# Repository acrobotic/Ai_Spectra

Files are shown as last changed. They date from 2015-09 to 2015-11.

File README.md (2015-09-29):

## Ai\_Spectra

PCB design files (EAGLE) for an interactive Light+Sound Electronics Board 
carrying 48 RGB LEDs, sensors, and a speaker for displaying custom audiovisual
patterns. 

## Description

For more details, check out the product page at:

   * https://acrobotic.com/acr-00018

Designed by ACROBOTIC Industries.  Please consider buying products from us to 
help fund future Open-Source projects like this! We’ll always put our best 
effort in every project, and release all our design files and code for you to 
use. 

## License

Released under the Creative Commons Attribution, Share-Alike license. Please 
check LICENSE.txt for more information. All text above must be included in any 
redistribution.

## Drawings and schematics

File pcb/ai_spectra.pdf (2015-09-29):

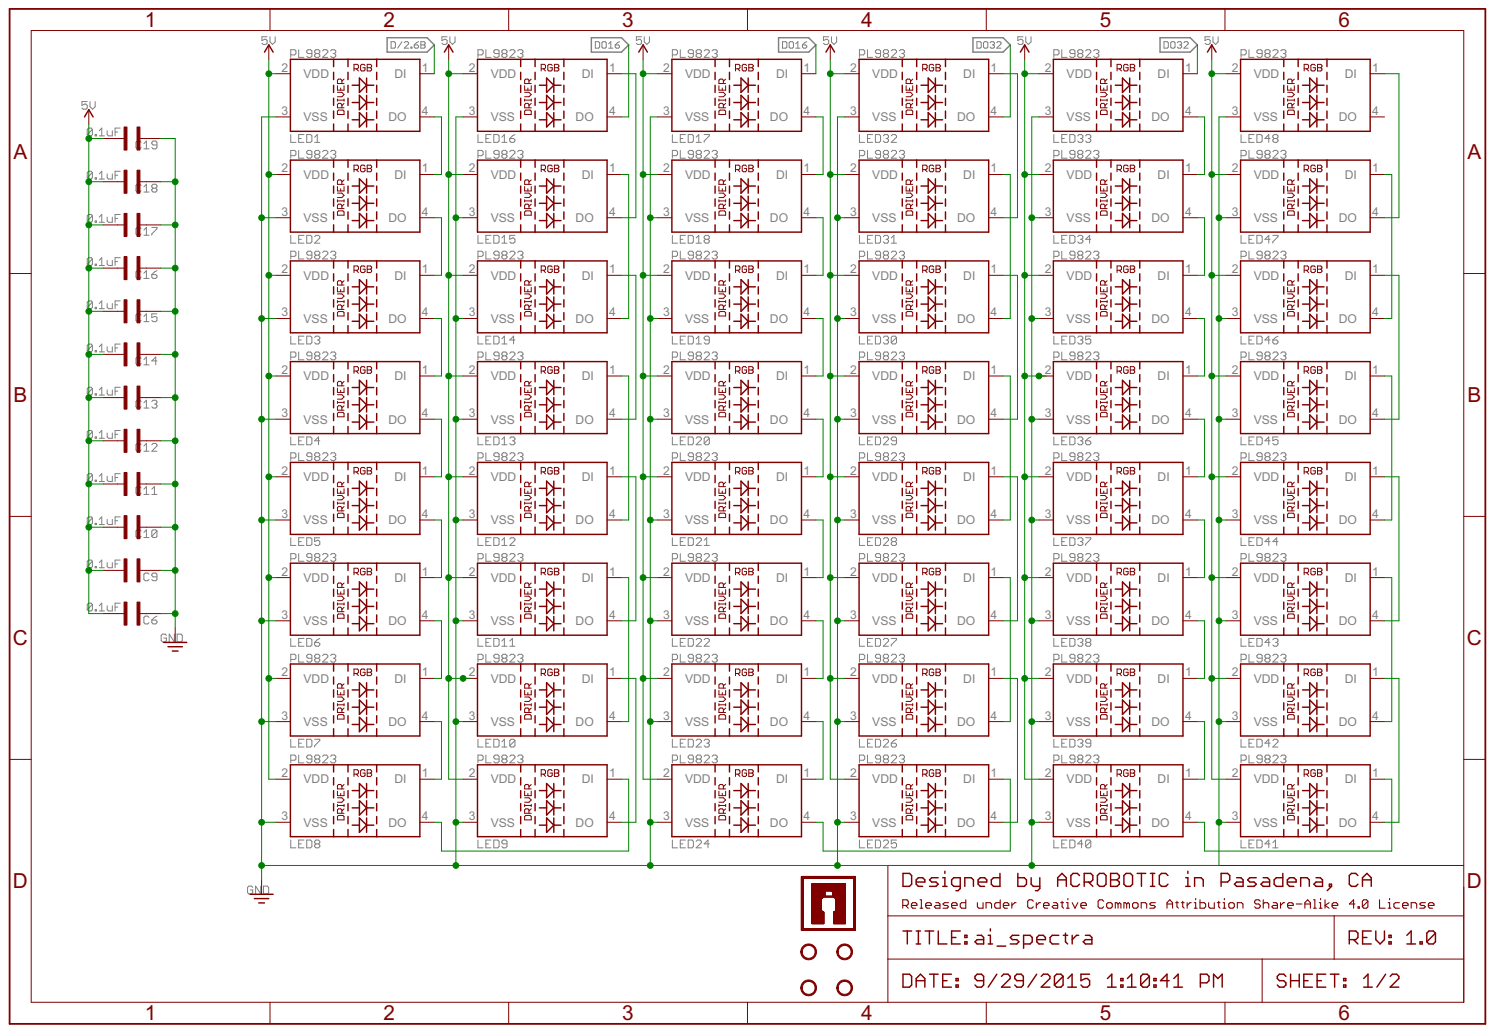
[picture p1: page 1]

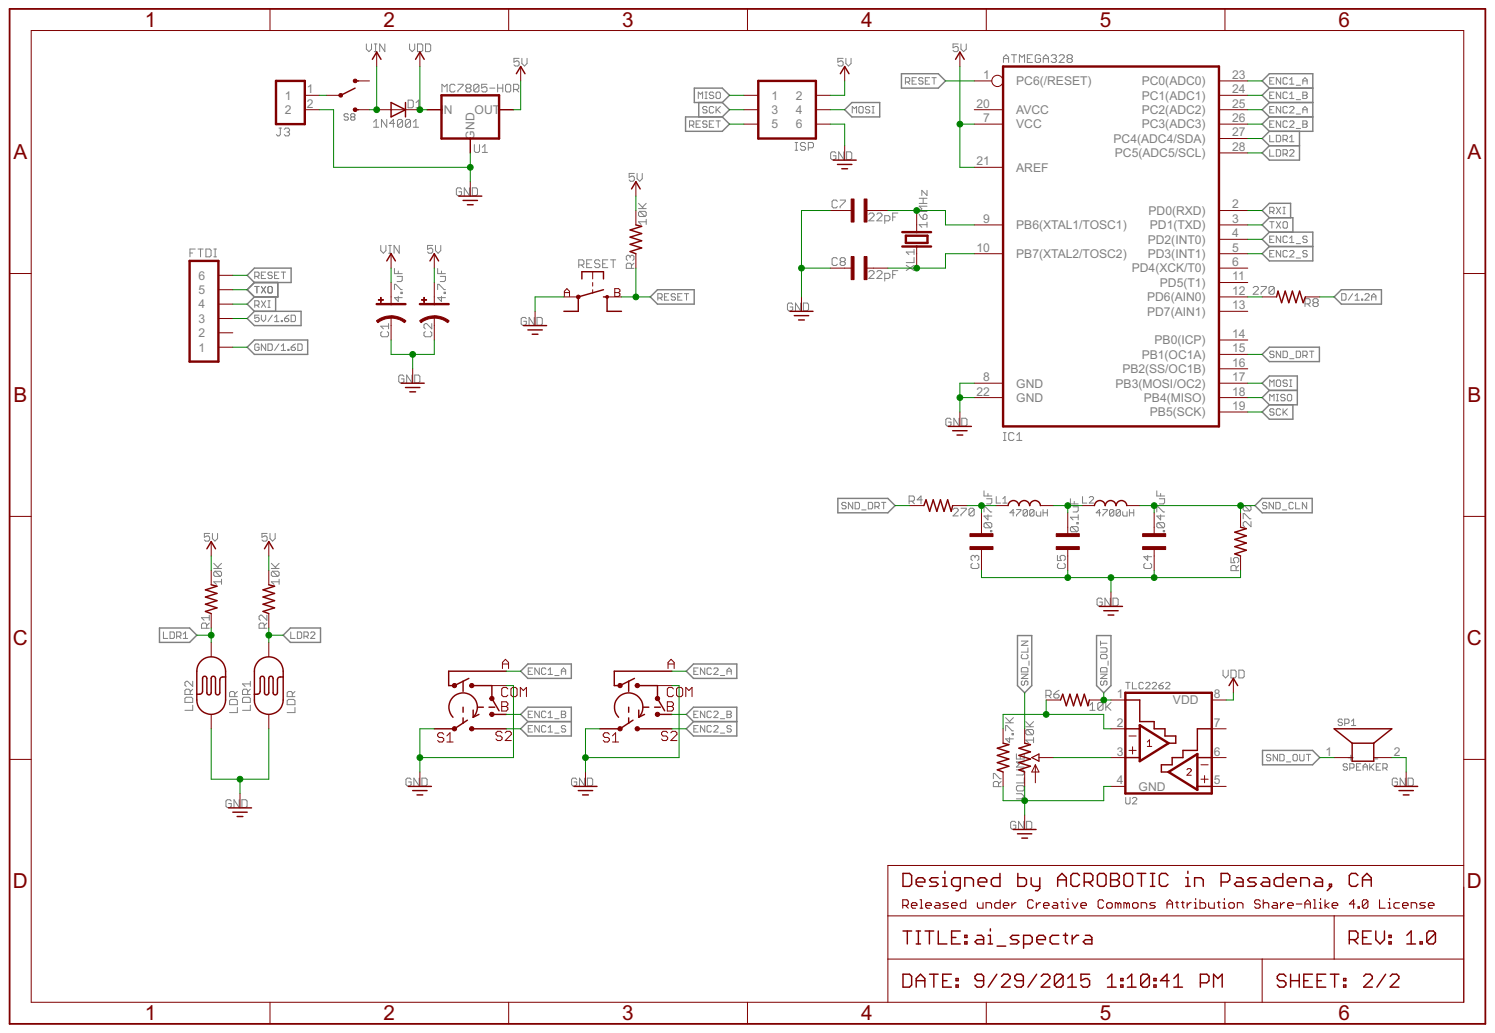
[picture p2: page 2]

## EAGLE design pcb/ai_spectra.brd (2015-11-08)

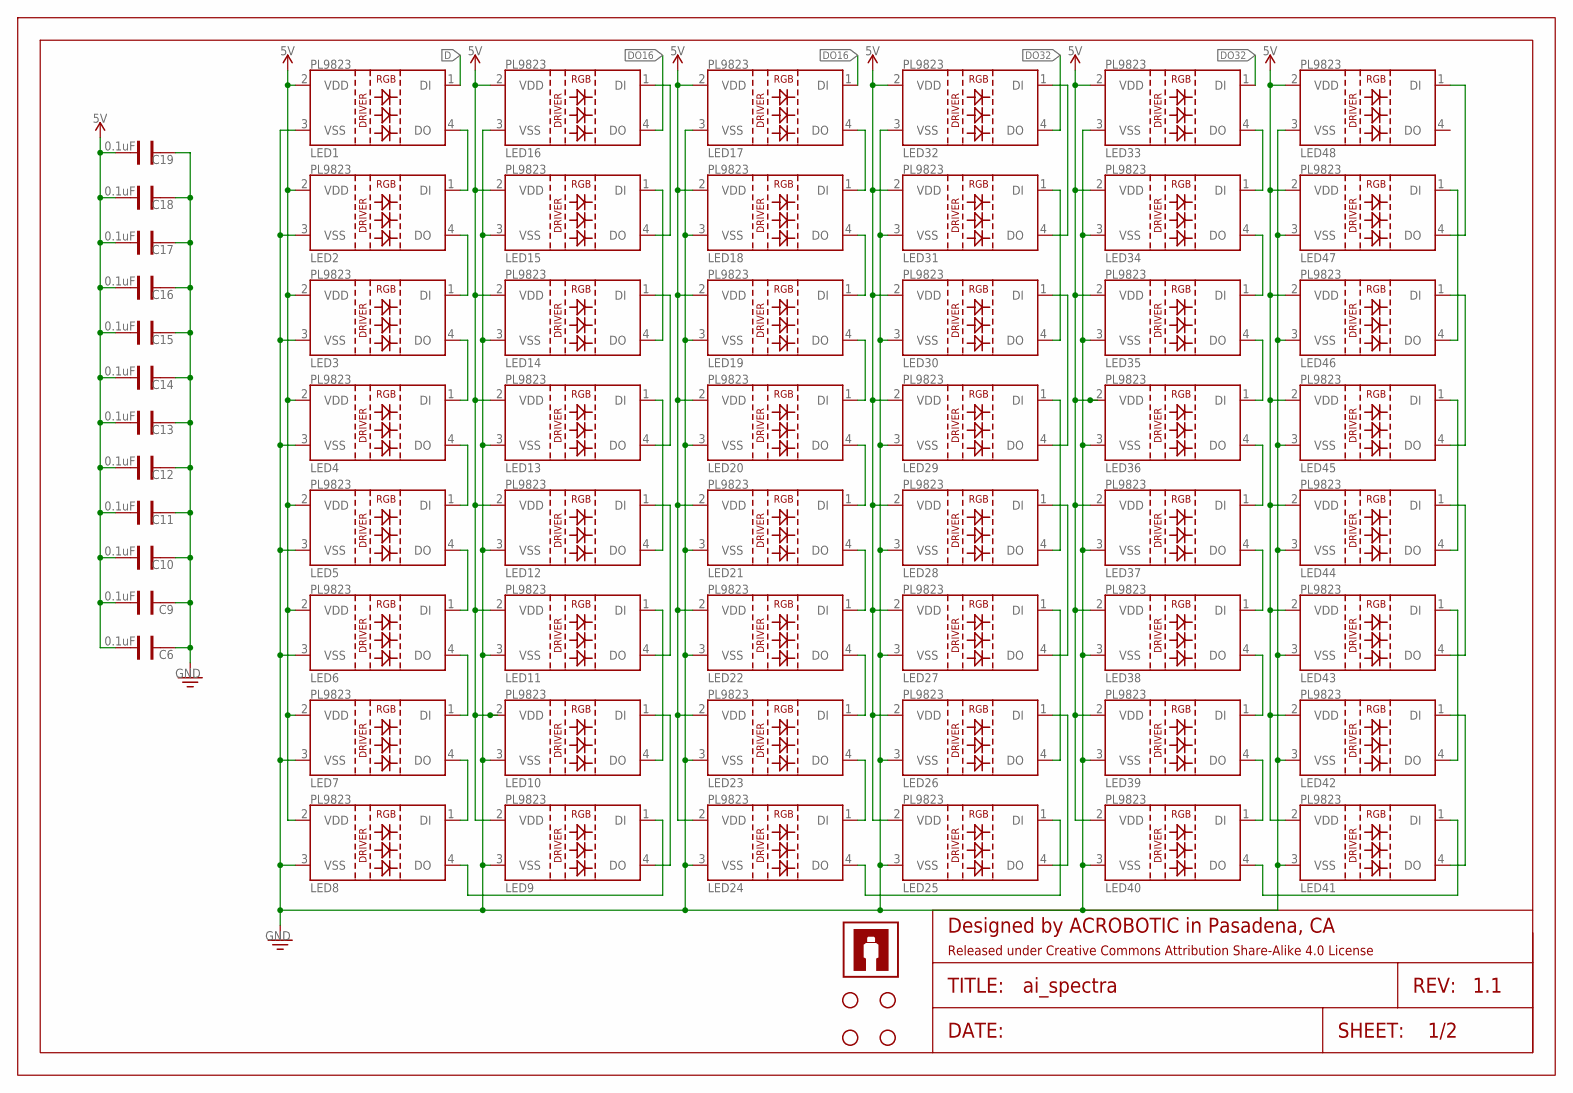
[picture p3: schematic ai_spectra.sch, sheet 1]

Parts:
C6, C9, C10, C11, C12, C13, C14, C15, C16, C17, C18, C19: 0.1uF; CAP-025X050
FRAME1: FRAME-LETTER; CREATIVE-COMMONS
LED1, LED2, LED3, LED4, LED5, LED6, LED7, LED8, LED9, LED10, LED11, LED12, LED13, LED14, LED15, LED16, LED17, LED18, LED19, LED20, LED21, LED22, LED23, LED24, LED25, LED26, LED27, LED28, LED29, LED30, LED31, LED32, LED33, LED34, LED35, LED36, LED37, LED38, LED39, LED40, LED41, LED42, LED43, LED44, LED45, LED46, LED47, LED48: LED-PL9823-F8
STANDOFF1, STANDOFF2, STANDOFF3, STANDOFF4: STAND-OFF4; STAND-OFF-4
U$18: AI-LOGOXS; AI-LOGO-XS

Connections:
5V: C6.1, C9.1, C10.1, C11.1, C12.1, C13.1, C14.1, C15.1, C16.1, C17.1, C18.1, C19.1, LED1.2 (VDD), LED2.2 (VDD), LED3.2 (VDD), LED4.2 (VDD), LED5.2 (VDD), LED6.2 (VDD), LED7.2 (VDD), LED8.2 (VDD), LED9.2 (VDD), LED10.2 (VDD), LED11.2 (VDD), LED12.2 (VDD), LED13.2 (VDD), LED14.2 (VDD), LED15.2 (VDD), LED16.2 (VDD), LED17.2 (VDD), LED18.2 (VDD), LED19.2 (VDD), LED20.2 (VDD), LED21.2 (VDD), LED22.2 (VDD), LED23.2 (VDD), LED24.2 (VDD), LED25.2 (VDD), LED26.2 (VDD), LED27.2 (VDD), LED28.2 (VDD), LED29.2 (VDD), LED30.2 (VDD), LED31.2 (VDD), LED32.2 (VDD), LED33.2 (VDD), LED34.2 (VDD), LED35.2 (VDD), LED36.2 (VDD), LED37.2 (VDD), LED38.2 (VDD), LED39.2 (VDD), LED40.2 (VDD), LED41.2 (VDD), LED42.2 (VDD), LED43.2 (VDD), LED44.2 (VDD), LED45.2 (VDD), LED46.2 (VDD), LED47.2 (VDD), LED48.2 (VDD); also elsewhere on the board
D: LED1.1 (DI); also elsewhere on the board
DO8: LED8.4 (DO), LED9.1 (DI)
DO16: LED16.4 (DO), LED17.1 (DI)
DO24: LED24.4 (DO), LED25.1 (DI)
DO32: LED32.4 (DO), LED33.1 (DI)
GND: C6.2, C9.2, C10.2, C11.2, C12.2, C13.2, C14.2, C15.2, C16.2, C17.2, C18.2, C19.2, LED1.3 (VSS), LED2.3 (VSS), LED3.3 (VSS), LED4.3 (VSS), LED5.3 (VSS), LED6.3 (VSS), LED7.3 (VSS), LED8.3 (VSS), LED9.3 (VSS), LED10.3 (VSS), LED11.3 (VSS), LED12.3 (VSS), LED13.3 (VSS), LED14.3 (VSS), LED15.3 (VSS), LED16.3 (VSS), LED17.3 (VSS), LED18.3 (VSS), LED19.3 (VSS), LED20.3 (VSS), LED21.3 (VSS), LED22.3 (VSS), LED23.3 (VSS), LED24.3 (VSS), LED25.3 (VSS), LED26.3 (VSS), LED27.3 (VSS), LED28.3 (VSS), LED29.3 (VSS), LED30.3 (VSS), LED31.3 (VSS), LED32.3 (VSS), LED33.3 (VSS), LED34.3 (VSS), LED35.3 (VSS), LED36.3 (VSS), LED37.3 (VSS), LED38.3 (VSS), LED39.3 (VSS), LED40.3 (VSS), LED41.3 (VSS), LED42.3 (VSS), LED43.3 (VSS), LED44.3 (VSS), LED45.3 (VSS), LED46.3 (VSS), LED47.3 (VSS), LED48.3 (VSS); also elsewhere on the board
unnamed: LED1.4 (DO), LED2.1 (DI)
unnamed: LED2.4 (DO), LED3.1 (DI)
unnamed: LED3.4 (DO), LED4.1 (DI)
unnamed: LED4.4 (DO), LED5.1 (DI)
unnamed: LED5.4 (DO), LED6.1 (DI)
unnamed: LED6.4 (DO), LED7.1 (DI)
unnamed: LED7.4 (DO), LED8.1 (DI)
unnamed: LED9.4 (DO), LED10.1 (DI)
unnamed: LED10.4 (DO), LED11.1 (DI)
unnamed: LED11.4 (DO), LED12.1 (DI)
unnamed: LED12.4 (DO), LED13.1 (DI)
unnamed: LED13.4 (DO), LED14.1 (DI)
unnamed: LED14.4 (DO), LED15.1 (DI)
unnamed: LED15.4 (DO), LED16.1 (DI)
unnamed: LED33.4 (DO), LED34.1 (DI)
unnamed: LED17.4 (DO), LED18.1 (DI)
unnamed: LED18.4 (DO), LED19.1 (DI)
unnamed: LED19.4 (DO), LED20.1 (DI)
unnamed: LED20.4 (DO), LED21.1 (DI)
unnamed: LED21.4 (DO), LED22.1 (DI)
unnamed: LED22.4 (DO), LED23.1 (DI)
unnamed: LED23.4 (DO), LED24.1 (DI)
unnamed: LED34.4 (DO), LED35.1 (DI)
unnamed: LED35.4 (DO), LED36.1 (DI)
unnamed: LED36.4 (DO), LED37.1 (DI)
unnamed: LED37.4 (DO), LED38.1 (DI)
unnamed: LED38.4 (DO), LED39.1 (DI)
unnamed: LED39.4 (DO), LED40.1 (DI)
unnamed: LED40.4 (DO), LED41.1 (DI)
unnamed: LED25.4 (DO), LED26.1 (DI)
unnamed: LED26.4 (DO), LED27.1 (DI)
unnamed: LED27.4 (DO), LED28.1 (DI)
unnamed: LED28.4 (DO), LED29.1 (DI)
unnamed: LED29.4 (DO), LED30.1 (DI)
unnamed: LED30.4 (DO), LED31.1 (DI)
unnamed: LED31.4 (DO), LED32.1 (DI)
unnamed: LED41.4 (DO), LED42.1 (DI)
unnamed: LED42.4 (DO), LED43.1 (DI)
unnamed: LED43.4 (DO), LED44.1 (DI)
unnamed: LED44.4 (DO), LED45.1 (DI)
unnamed: LED45.4 (DO), LED46.1 (DI)
unnamed: LED46.4 (DO), LED47.1 (DI)
unnamed: LED47.4 (DO), LED48.1 (DI)

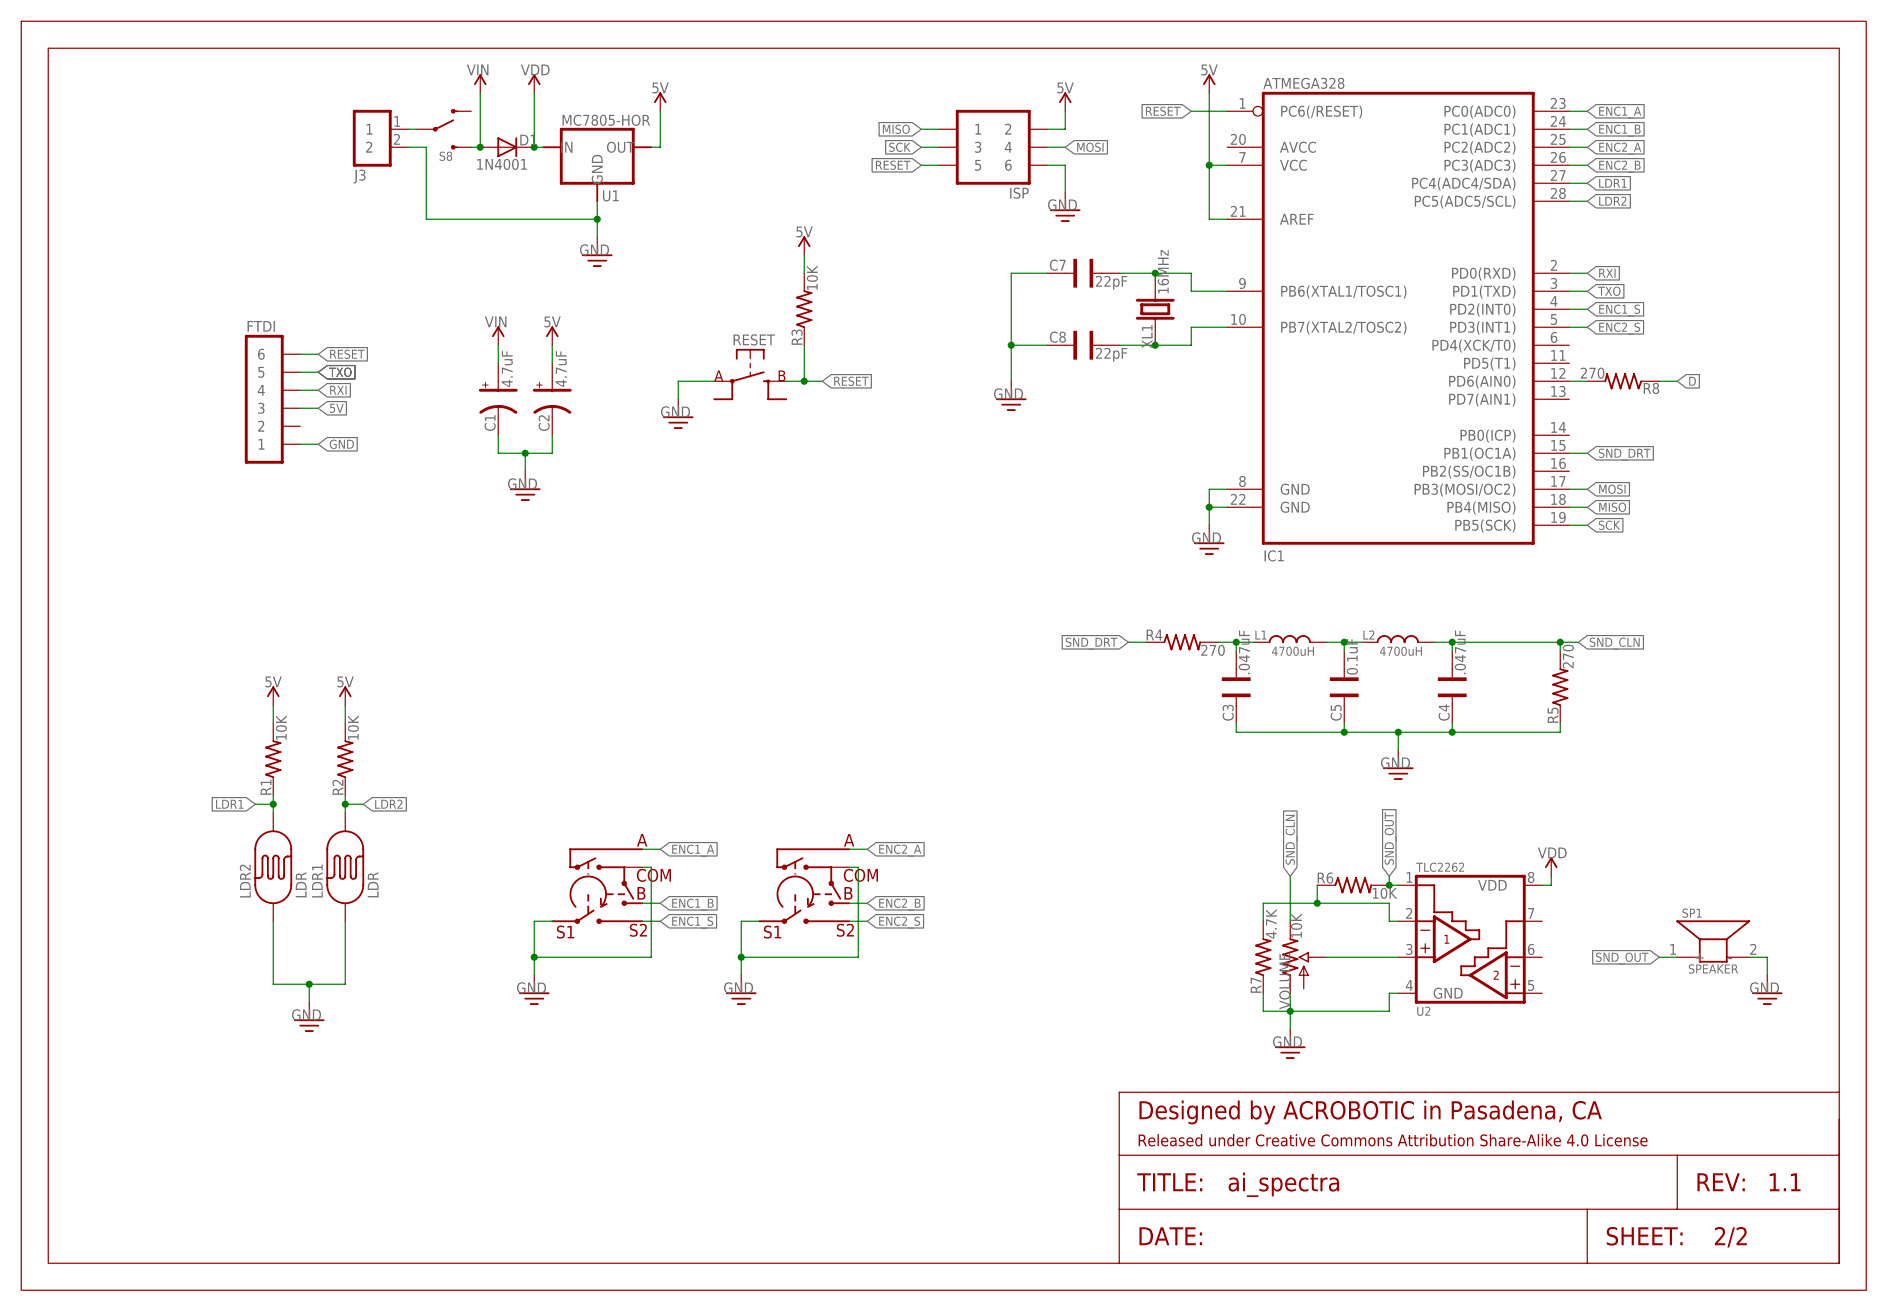
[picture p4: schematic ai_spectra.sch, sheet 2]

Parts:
C1, C2: 4.7uF; CAP-POL-025X50
C3, C4: .047uF; CAP-025X050
C5: 0.1uF; CAP-025X050
C7, C8: 22pF; CAP-025X050
D1: 1N4001; TH-1N914
ENC1, ENC2: ROT-ENC; ROTENC-12MM-SW
FRAME2: FRAME-LETTER; CREATIVE-COMMONS
FTDI: 1X06
IC1: ATMEGA328P-PDIP; DIL28
ISP: 2X03
J3: 1X02ST; 1X02-ST
L1, L2: 4700uH; RLB0912
LDR1, LDR2: LDR-PTH; LDR
R1, R2, R3, R6: 10K; RES-AXIAL-0.4
R4, R5, R8: 270; RES-AXIAL-0.4
R7: 4.7K; RES-AXIAL-0.4
RESET: SW-SPSTTH06X06; SW-SPST-TH06X06
S8: SW-SPDTTH; SW-SPDT-TH
SP1: SPEAKER; AL30P
U1: MC7805-HOR; TO220
U2: TLC2262; DIL08
VOLUME: 10K; POT-05X05
XL1: 16MHz; HC49S

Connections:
5V: C2.A, FTDI.3, IC1.7 (VCC), IC1.21 (AREF), ISP.2, R1.P$2 (2), R2.P$2 (2), R3.P$2 (2), U1.OUT; also elsewhere on the board
D: R8.P$1 (1); also elsewhere on the board
ENC1_A: ENC1.P3 (A), IC1.23 (PC0(ADC0))
ENC1_B: ENC1.P1 (B), IC1.24 (PC1(ADC1))
ENC1_S: ENC1.P5 (S2), IC1.4 (PD2(INT0))
ENC2_A: ENC2.P3 (A), IC1.25 (PC2(ADC2))
ENC2_B: ENC2.P1 (B), IC1.26 (PC3(ADC3))
ENC2_S: ENC2.P5 (S2), IC1.5 (PD3(INT1))
GND: C1.C, C2.C, C3.2, C4.2, C5.2, C7.2, C8.2, ENC1.P2 (COM), ENC1.P4 (S1), ENC2.P2 (COM), ENC2.P4 (S1), FTDI.1, IC1.8 (GND), IC1.22 (GND), ISP.6, J3.2, LDR1.1, LDR2.1, R5.P$1 (1), R7.P$1 (1), RESET.A@1 (A), SP1.2 (-), U1.GND, U2.4 (GND), VOLUME.3 (A); also elsewhere on the board
LDR1: IC1.27 (PC4(ADC4/SDA)), LDR2.2, R1.P$1 (1)
LDR2: IC1.28 (PC5(ADC5/SCL)), LDR1.2, R2.P$1 (1)
MISO: IC1.18 (PB4(MISO)), ISP.1
MOSI: IC1.17 (PB3(MOSI/OC2)), ISP.4
unnamed: U2.3 (1IN+), VOLUME.2 (S)
unnamed: C8.1, IC1.10 (PB7(XTAL2/TOSC2)), XL1.1
unnamed: C7.1, IC1.9 (PB6(XTAL1/TOSC1)), XL1.2
unnamed: J3.1, S8.2 (COM)
unnamed: C3.1, L1.2, R4.P$2 (2)
unnamed: C5.1, L1.1, L2.2
unnamed: R6.P$1 (1), R7.P$2 (2), U2.2 (1IN-)
unnamed: IC1.12 (PD6(AIN0)), R8.P$2 (2)
RESET: FTDI.6, IC1.1 (PC6(/RESET)), ISP.5, R3.P$1 (1), RESET.B@1 (B)
RXI: FTDI.4, IC1.2 (PD0(RXD))
SCK: IC1.19 (PB5(SCK)), ISP.3
SND_CLN: C4.1, L2.1, R5.P$2 (2), VOLUME.1 (E)
SND_DRT: IC1.15 (PB1(OC1A)), R4.P$1 (1)
SND_OUT: R6.P$2 (2), SP1.1 (+), U2.1 (1OUT)
TXO: FTDI.5, IC1.3 (PD1(TXD))
VDD: D1.C, U1.IN, U2.8 (VDD)
VIN: C1.A, D1.A, S8.3 (L2)

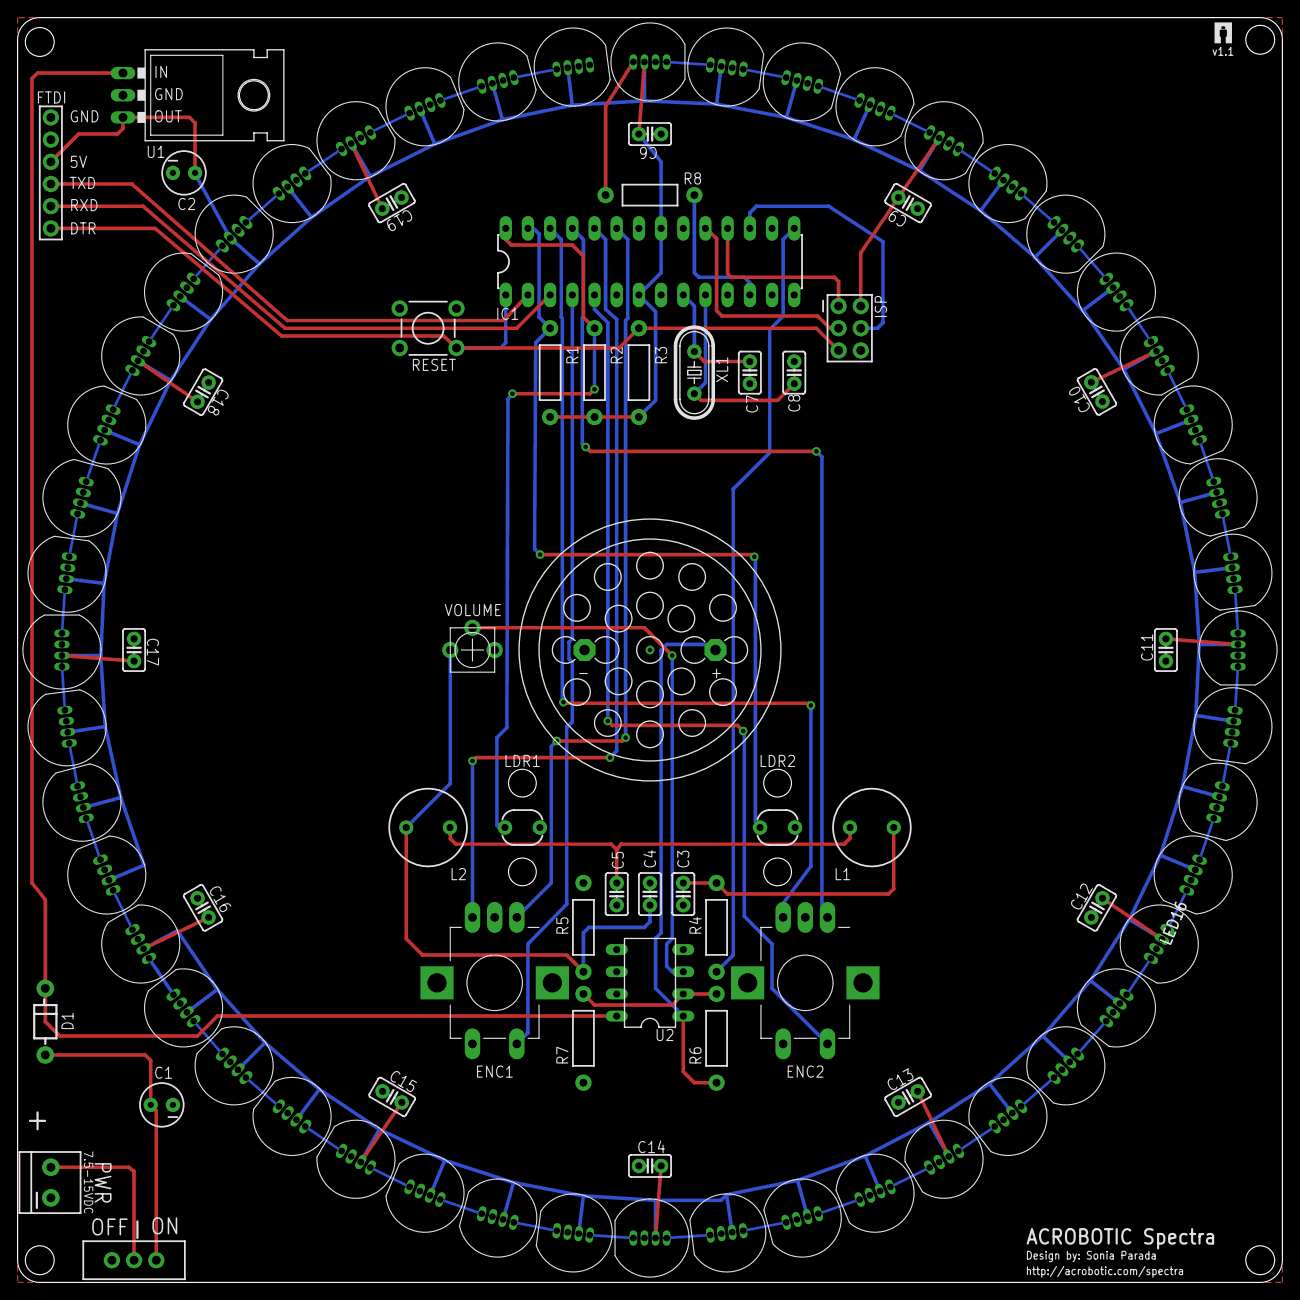
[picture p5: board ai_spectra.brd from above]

Board: 2 copper layers, 144.8 x 144.8 mm, 100 parts (0 on the bottom side), 77 nets.

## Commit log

2015-09-26 first commit.
    [ai_spectra.brd, ai_spectra.sch]
2015-09-28 adding gerbers
    [ai_spectra.brd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]
2015-09-29 updating license, and schematic
    [ai_spectra.brd, ai_spectra.sch]
2015-11-08 updating LED spacing
    [ai_spectra.brd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]
2015-11-08 updating attribute
    [ai_spectra.brd, ai_spectra.sch]

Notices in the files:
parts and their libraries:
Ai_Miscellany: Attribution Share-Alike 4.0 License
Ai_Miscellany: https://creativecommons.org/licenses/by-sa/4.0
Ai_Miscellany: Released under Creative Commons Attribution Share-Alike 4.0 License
